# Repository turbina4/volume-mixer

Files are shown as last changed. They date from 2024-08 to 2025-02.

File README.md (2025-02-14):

# Arduino-Based Volume Mixer Controller

## Overview

This application allows you to control the volume of various applications on your computer using an Arduino and potentiometers. By adjusting the potentiometers, you can easily control the volume levels of specified applications or system sounds like master volume and microphone volume.
Components

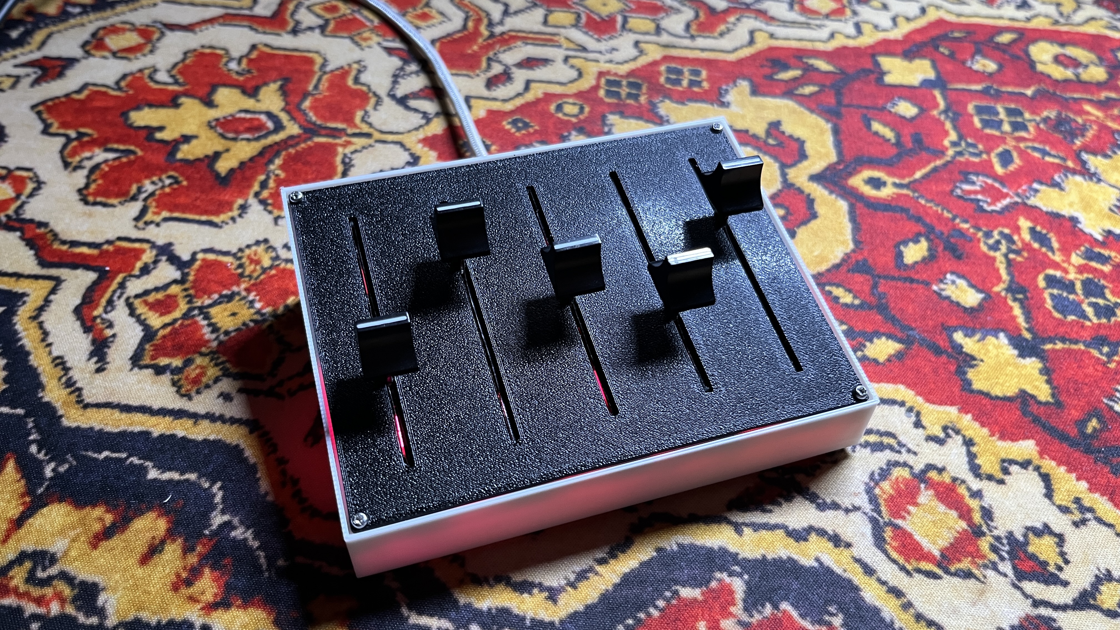
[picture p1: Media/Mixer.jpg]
Mixer Photo


## 3D-Printed case

A custom 3D-printed case for the Arduino Pro Micro enhances both aesthetics and functionality, providing easy access to potentiometers and secure mounting for components. The project utilizes:

-   4x M2x6 screws
-   6x M3x8 screws
-   6x M3 brass inserts (length: 4mm, diameter: 4.5mm)

## Schematic

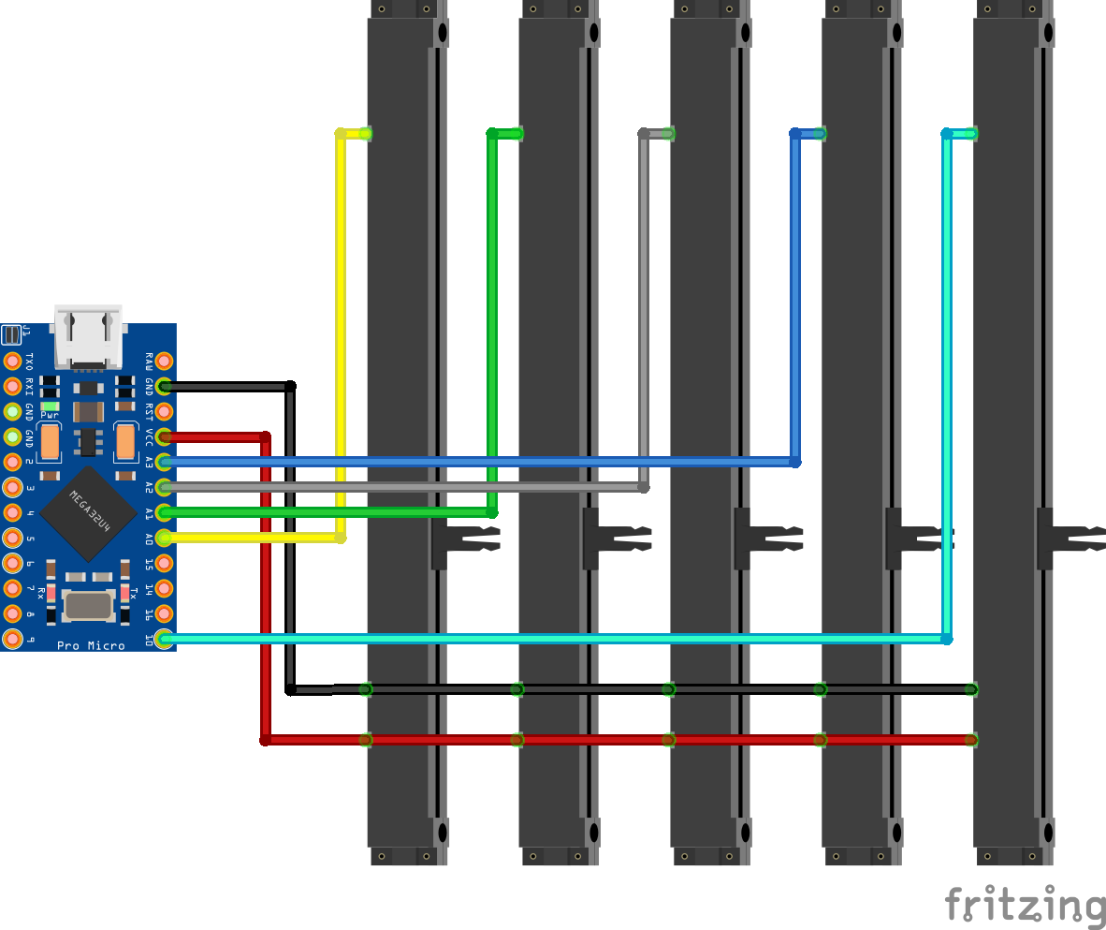
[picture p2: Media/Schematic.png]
Schematic img


## Configuration

The configuration file (config.yaml) specifies the settings for your COM port, baud rate, and the applications you want to control. Here's a sample configuration:

#### Special Controls

-   master: Controls the overall system volume.
-   mic: Controls the microphone volume.
-   activeWindow: Controls currently focused app.

#### Application Grouping

By grouping applications together, you can control the volume of multiple applications simultaneously.

### Example Config:

```yaml
# How to edit the config:

# port: 
    #AUTO - automaticly detects port (Experimental feature)
    #manual - Check your COM port in Device Manager (It should look like this -> port: COMx)
port: AUTO

# baudrate: Same Baud Rate as the one in arduinoCode.ino
baudrate: 115200

# invertSliders: Explains itself
invertSliders: false

# apps: List your apps here
#       Check the application name in Task Manager -> Details
#       App names are not case sensitive
#       Special controls: master - controls master volume
#                         mic - controls your microphone volume
#                         activeWindow - controls currently focused window volume 
#       group: Group multiple apps together
apps:
    - master
    - firefox
    - activeWindow
    - Discord
    - group:
            - PathOfExileSteam
            - cs2
            - GeometryDash
            - RustClient
```

## Installation

Download `Mixer.Software.msi` and install the program.

## Usage

Connect the Arduino to your computer and upload the provided sketch.

Configure the application using the provided config.yaml file, ensuring the COM port and baud rate match those in the Arduino sketch.

Run the application on your computer. It will read the potentiometer values from the Arduino and adjust the specified application volumes accordingly.

If you got any error while opening Serial Port make sure you have correct config options and press `Reload config` in menu

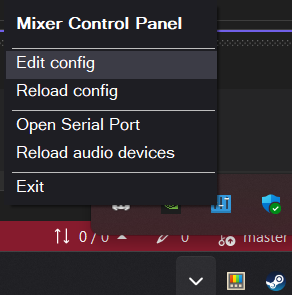
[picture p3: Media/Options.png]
Options img


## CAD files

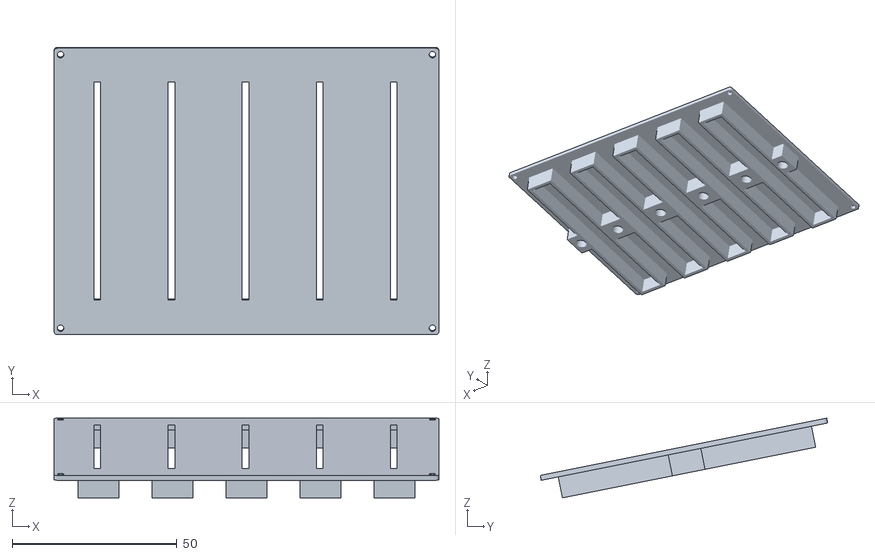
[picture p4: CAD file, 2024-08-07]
3D Model/volume-mixer Plate.stl
117.0 x 87.4 x 24.2

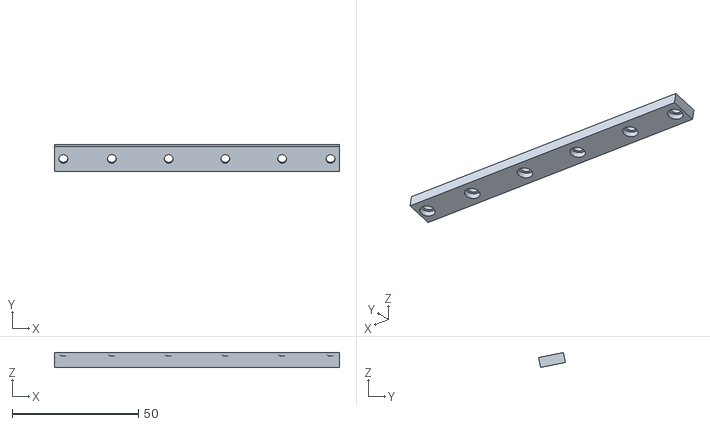
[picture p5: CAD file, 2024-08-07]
3D Model/volume-mixer SliderHolder.stl
113.0 x 10.7 x 5.90

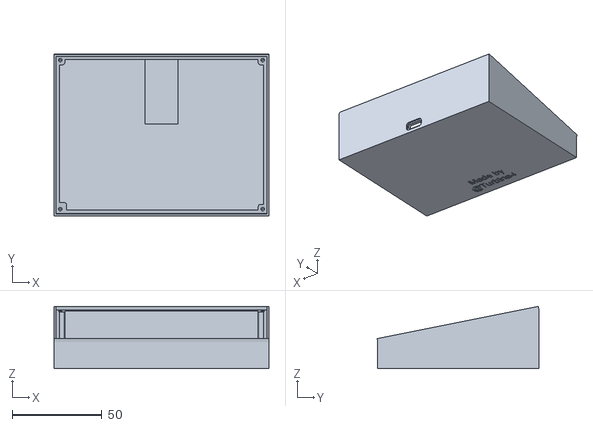
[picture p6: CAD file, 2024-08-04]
3D Model/volume-mixer Body.stl
120.0 x 90.4 x 34.8

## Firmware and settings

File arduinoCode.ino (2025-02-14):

// Uncomment if you want to enable LEDS
// #define ENABLE_LEDS 

const int NUM_SLIDERS = 5;
const int analogInputs[NUM_SLIDERS] = { A10, A3, A2, A1, A0 };  //Change to your pinout


#ifdef ENABLE_LEDS
#include <FastLED.h>

#define NUM_LEDS 6
#define DATA_PIN 9
CRGB leds[NUM_LEDS];

const long intervalChangeLEDS = 20;
unsigned long previousMillisChangeLEDS = 0;

void setColor(int r, int g, int b) {
  for (int i = 0; i < NUM_LEDS; i++) {
    leds[i] = CRGB(r, g, b);
  }
  FastLED.show();
}
#endif


const int hysteresis = 2;

const long intervalSendData = 100;
unsigned long previousMillisSendData = 0;

int analogSliderValues[NUM_SLIDERS];
int analogSliderValuesOldData[NUM_SLIDERS] = { -1 };


void setup() {
  for (int i = 0; i < NUM_SLIDERS; i++) {
    pinMode(analogInputs[i], INPUT);
  }

#ifdef ENABLE_LEDS
  FastLED.addLeds<WS2812B, DATA_PIN, GRB>(leds, NUM_LEDS);
  FastLED.setBrightness(255);
#endif

  Serial.begin(115200);

  while (!Serial)
#ifdef ENABLE_LEDS
    setColor(255, 0, 0);
#endif

  sendFirstValues();
}


void loop() {
  unsigned long currentMillis = millis();

  if (currentMillis - previousMillisSendData >= intervalSendData) {
    previousMillisSendData = currentMillis;
    updateSliderValues();
    sendSliderValues();
  }


#ifdef ENABLE_LEDS
  if (currentMillis - previousMillisChangeLEDS >= intervalChangeLEDS) {
    previousMillisChangeLEDS = currentMillis;
    static uint8_t startIndex = 0;
    fill_rainbow(leds, NUM_LEDS, startIndex, 10);
    FastLED.show();
    startIndex++;
  }
#endif
}


void updateSliderValues() {
  for (int i = 0; i < NUM_SLIDERS; i++) {
    analogSliderValues[i] = map(analogRead(analogInputs[i]), 0, 1020, 0, 100);
  }
}


void sendSliderValues() {
  String builtString = "";

  for (int i = 0; i < NUM_SLIDERS; i++) {
    int currentValue = analogSliderValues[i];
    int oldValue = analogSliderValuesOldData[i];

    bool isSignificantChange = abs(currentValue - oldValue) >= hysteresis;

    bool isEdgeValueChanged = (currentValue == 0 || currentValue == 100) && currentValue != oldValue;

    if (oldValue == -1 || isSignificantChange || isEdgeValueChanged) {
      builtString += String(i) + ":" + String(currentValue) + "\n";
      analogSliderValuesOldData[i] = currentValue;
    }
  }

  if (builtString.length() > 0)
    Serial.print(builtString);
}


void sendFirstValues() {
  String builtString = "";

  for (int i = 0; i < NUM_SLIDERS; i++) {
    int currentValue = analogSliderValues[i];
    builtString += String(i) + ":" + String(currentValue) + "\n";
    analogSliderValuesOldData[i] = currentValue;
  }

  if (builtString.length() > 0)
    Serial.print(builtString);
}

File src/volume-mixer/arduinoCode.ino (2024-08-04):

const int NUM_SLIDERS = 5;
const int analogInputs[NUM_SLIDERS] = { A0, A1, A2, A3, A4 }; //Change it to analog pins on your arduino

int analogSliderValues[NUM_SLIDERS];

unsigned long previousMillisSendData = 0;
const long intervalSendData = 50;

void setup() {
  for (int i = 0; i < NUM_SLIDERS; i++) {
    pinMode(analogInputs[i], INPUT);
  }

  Serial.begin(57600);
}

void loop() {
  unsigned long currentMillis = millis();

  if (currentMillis - previousMillisSendData >= intervalSendData) {
    previousMillisSendData = currentMillis;
    updateSliderValues();
    sendSliderValues();
  }
}

void updateSliderValues() {
  for (int i = 0; i < NUM_SLIDERS; i++) {
    analogSliderValues[i] = map(analogRead(analogInputs[i]), 0, 1023, 0, 100);
  }
}

void sendSliderValues() {
  String builtString = String("");

  for (int i = 0; i < NUM_SLIDERS; i++) {
    builtString += String((int)analogSliderValues[i]);

    if (i < NUM_SLIDERS - 1) {
      builtString += String("|");
    }
  }

  Serial.println(builtString);
}

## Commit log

2024-08-04 Update arduino communication
2024-08-04 Update Readme, Add 3d model for case
    [volume-mixer Body.stl, volume-mixer Plate.stl, volume-mixer SliderHolder.stl]
2024-08-07 Add auto port, change arduino code
2024-08-07 Update Readme, Change arduinoCode.ino dir, Update 3D Models
    [volume-mixer Plate.stl, volume-mixer SliderHolder.stl]
2024-08-17 Update schematic and arduinoCode.ino
